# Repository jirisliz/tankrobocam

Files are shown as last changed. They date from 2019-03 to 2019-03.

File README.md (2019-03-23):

# TankRoboCam

Simple robotic tank with camera wifi controlled. 

## Parts

 - **DC motor driver**: L298N DC Stepper Motor Driver Module Dual H Bridge Control Board for Arduino
 - **ESP32 camera board**: M5Stack ESP32 Development Board 3D Wifi Antenna Mini Camera Module
 - **Tank chassis**: Smart Robot Tank Car Chassis Kit Rubber Track Crawler for Arduino 130 Motor
 - **DC-DC Step up**: MT3608 2A DC-DC Step Up Power Apply Module Booster Power Module for Arduino
 - **Arduino MCU**: Mini/Nano ATmega328P/ATmega168P CH340G/FT232 3.3/5V micro-controller Arduino

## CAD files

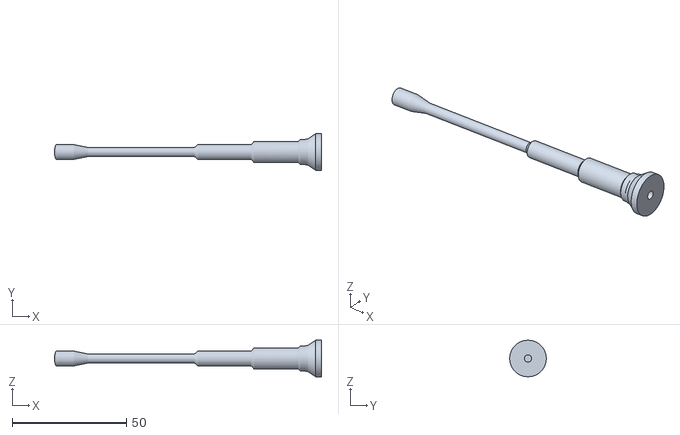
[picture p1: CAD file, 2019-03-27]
3d/Cannon.stl
116.9 x 16.0 x 16.0

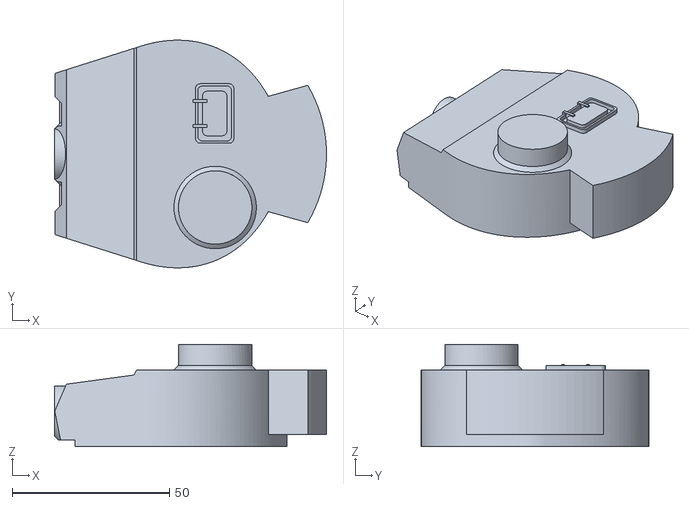
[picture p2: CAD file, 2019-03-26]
3d/Tower.stl
86.5 x 72.4 x 32.4

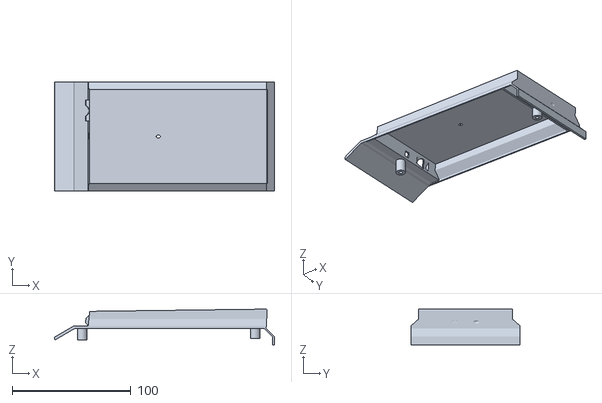
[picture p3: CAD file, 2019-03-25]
3d/RoboTankBody.stl
185.5 x 92.0 x 30.2

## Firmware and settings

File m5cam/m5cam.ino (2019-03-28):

/**
 * Based on https://github.com/mic159/m5cam
 * 
 * Reads an image from the camera and servers it to a connected client.
 * Starts a webserver and starts streaming when a client connects
 * 
 * After the device has started change your computer's WiFi to m5cam 
 * and open the browser at http://192.168.4.1 for a stream
 * or http://192.168.4.1/camera for a still picture
 */
//#define CONFIG_ENABLE_TEST_PATTERN n
#define CONFIG_OV2640_SUPPORT y
//#define CONFIG_OV7725_SUPPORT y
#define CONFIG_ESP32_DEFAULT_CPU_FREQ_240 y
#define CONFIG_ESP32_DEFAULT_CPU_FREQ_MHZ 240
#define CONFIG_MEMMAP_SMP y
#define CONFIG_TASK_WDT n
#define CONFIG_LOG_DEFAULT_LEVEL_INFO y
#define CONFIG_LOG_DEFAULT_LEVEL 3
#define CONFIG_D0 17
#define CONFIG_D1 35
#define CONFIG_D2 34
#define CONFIG_D3 5
#define CONFIG_D4 39
#define CONFIG_D5 18
#define CONFIG_D6 36
#define CONFIG_D7 19
#define CONFIG_XCLK 27
#define CONFIG_PCLK 21
#define CONFIG_VSYNC 22
#define CONFIG_HREF 26
#define CONFIG_SDA 25
#define CONFIG_SCL 23
#define CONFIG_RESET 15
#define CONFIG_XCLK_FREQ 20000000
#define CAMERA_PIXEL_FORMAT CAMERA_PF_JPEG
#define CAMERA_FRAME_SIZE CAMERA_FS_QVGA
#define CAMERA_LED_GPIO 17


#include <WiFi.h>
#include <esp_wifi.h>
#include <lwip/err.h>
#include <lwip/sockets.h>
#include "camera.h"
#include "canvas_htm.h"
#include <WebSocketsServer.h>
#include <SoftwareSerial.h>

#define RXD2 12
#define TXD2 16   // Instead of LED

IPAddress apIP(192, 168, 4, 1);

const char* ssid     = "TankRobot-192.168.4.1";
const char* pass     = "prahasucks";

WebSocketsServer webSocket = WebSocketsServer(443);
WiFiServer server(80);

SoftwareSerial SWSeral2(RXD2, TXD2);

void stopMotors()
{
  SWSeral2.printf("stop-#");
}

void webSocketEvent(uint8_t num, WStype_t type, uint8_t * payload, size_t length) {

  switch (type) {
    case WStype_DISCONNECTED:
      Serial.printf("[%u] Disconnected!\n", num);
      // Stop motors
      stopMotors();
      
      break;
    case WStype_CONNECTED: {
        IPAddress ip = webSocket.remoteIP(num);
        Serial.printf("[%u] Connected from %d.%d.%d.%d url: %s\n", num, ip[0], ip[1], ip[2], ip[3], payload);

        // send message to client
        webSocket.sendTXT(num, "Connected");
      }
      break;
    case WStype_TEXT:
      //Serial.printf("[%u] get Text: %s\n", num, payload);
      Serial.printf("%s\n", payload);
      SWSeral2.printf("%s\n", payload);

      break;
    case WStype_ERROR:
    case WStype_FRAGMENT_TEXT_START:
    case WStype_FRAGMENT_BIN_START:
    case WStype_FRAGMENT:
    case WStype_FRAGMENT_FIN:
      break;
  }

}

void serve()
{
  WiFiClient client = server.available();
  if (client) 
  {
    //Serial.println("New Client.");
    String currentLine = "";
    while (client.connected()) 
    {
      webSocket.loop();
      if (client.available()) 
      {
        char c = client.read();
        //Serial.write(c);
        if (c == '\n') 
        {
          if (currentLine.length() == 0) 
          {
            client.println("HTTP/1.1 200 OK");
            client.println("Content-type:text/html");
            client.println();
            client.print(canvas_htm);
            client.println();
            break;
          } 
          else 
          {
            currentLine = "";
          }
        } 
        else if (c != '\r') 
        {
          currentLine += c;
        }
        
        if(currentLine.endsWith("GET /camera"))
        {
            client.println("HTTP/1.1 200 OK");
            client.println("Content-type:image/jpeg");
            client.println();

              esp_err_t err = camera_run();
              if (err != ESP_OK) {
                  ESP_LOGW(TAG, "Camera capture failed with error = %d", err);
                  return;
              }
            
              size_t frame_size = camera_get_data_size();
              uint8_t* fb = camera_get_fb();
            

              client.write(fb, frame_size);
              

        }
      }
    }
    // close the connection:
    client.stop();
    //Serial.println("Client Disconnected.");
  }  
}



static camera_pixelformat_t s_pixel_format;
bool video_running = false;

int udp_server = -1;
struct sockaddr_in destination;

void setup() {
  esp_log_level_set("camera", ESP_LOG_DEBUG);
  Serial.begin(115200);
  SWSeral2.begin(9600);
  esp_err_t err;

  ESP_ERROR_CHECK(gpio_install_isr_service(0));
  //pinMode(CAMERA_LED_GPIO, OUTPUT);
  //digitalWrite(CAMERA_LED_GPIO, LOW);
  Serial.println("Camera LED init.");
  
  WiFi.disconnect(true);

  camera_config_t camera_config;
  camera_config.ledc_channel = LEDC_CHANNEL_0;
  camera_config.ledc_timer = LEDC_TIMER_0;
  camera_config.pin_d0 = CONFIG_D0;
  camera_config.pin_d1 = CONFIG_D1;
  camera_config.pin_d2 = CONFIG_D2;
  camera_config.pin_d3 = CONFIG_D3;
  camera_config.pin_d4 = CONFIG_D4;
  camera_config.pin_d5 = CONFIG_D5;
  camera_config.pin_d6 = CONFIG_D6;
  camera_config.pin_d7 = CONFIG_D7;
  camera_config.pin_xclk = CONFIG_XCLK;
  camera_config.pin_pclk = CONFIG_PCLK;
  camera_config.pin_vsync = CONFIG_VSYNC;
  camera_config.pin_href = CONFIG_HREF;
  camera_config.pin_sscb_sda = CONFIG_SDA;
  camera_config.pin_sscb_scl = CONFIG_SCL;
  camera_config.pin_reset = CONFIG_RESET;
  camera_config.xclk_freq_hz = CONFIG_XCLK_FREQ;

  camera_model_t camera_model;
  err = camera_probe(&camera_config, &camera_model);
  if (err != ESP_OK) {
      ESP_LOGE(TAG, "Camera probe failed with error 0x%x", err);
      return;
  }

  if (camera_model == CAMERA_OV7725) {
      s_pixel_format = CAMERA_PIXEL_FORMAT;
      camera_config.frame_size = CAMERA_FRAME_SIZE;
      ESP_LOGI(TAG, "Detected OV7725 camera, using %s bitmap format",
              CAMERA_PIXEL_FORMAT == CAMERA_PF_GRAYSCALE ?
                      "grayscale" : "RGB565");
  } else if (camera_model == CAMERA_OV2640) {
      ESP_LOGI(TAG, "Detected OV2640 camera, using JPEG format");
      s_pixel_format = CAMERA_PF_JPEG;
      camera_config.frame_size = CAMERA_FRAME_SIZE;
      camera_config.jpeg_quality = 15;
  } else {
      ESP_LOGE(TAG, "Camera not supported");
      return;
  }
  Serial.println("Camera selected.");

  camera_config.pixel_format = s_pixel_format;
  err = camera_init(&camera_config);
  if (err != ESP_OK) {
      ESP_LOGE(TAG, "Camera init failed with error 0x%x", err);
      return;
  }
  Serial.println("Camera init.");

  ESP_LOGI("Starting WiFi AP m5cam");

  WiFi.mode(WIFI_AP);
  WiFi.softAPConfig(apIP, apIP, IPAddress(255, 255, 255, 0));
  WiFi.softAP(ssid, pass);

  webSocket.begin();
  webSocket.onEvent(webSocketEvent);
  Serial.println("Websockets server started");

  Serial.print("IP address: ");
  Serial.println(WiFi.softAPIP());

  server.begin();
  
  stopMotors();
}

unsigned long previousMillis = 0;
void loop() {
  serve();
}

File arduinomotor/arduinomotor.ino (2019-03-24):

#include "motors.h"

// HW serial port Serial1 pins RX D0 and TX D1 (only RX is realy used)

void setup()
{
  Serial.begin(9600); //This pipes to the serial monitor
  Serial1.begin(9600);

  motorsInit();
}

String cmd;

void loop()
{
  while (Serial.available()) {
    char c = Serial.read();
    cmd += c;
    if (c == '\n')
    {
      parseCmd(cmd);
      cmd = "";
    }
  }

}

/**
   Parses and executes command in form <command>-<value>#
*/
void parseCmd(String cmd)
{
  String strCmd;
  String strValue;
  if(cmd.indexOf("-") > 0)
  {
    strCmd = cmd.substring(0, cmd.indexOf("-"));
    strValue = cmd.substring(cmd.indexOf("-") + 1, cmd.indexOf("\n"));
  }
  else if(cmd.indexOf("\n") > 0)
  {
    strCmd = cmd.substring(0, cmd.indexOf("#"));
  }
  else return;
  
  Serial.println("strCmd: " + strCmd);
  Serial.println("strValue: " + strValue);

  
    if (strCmd.indexOf("LF") >= 0)
    {
    leftMotorForward(strValue.toInt());
    Serial.print(cmd);
    }
    if (strCmd.indexOf("LB") >= 0)
    {
    leftMotorBackward(strValue.toInt());
    Serial.print(cmd);
    }
    if (strCmd.indexOf("RF") >= 0)
    {
    rightMotorForward(strValue.toInt());
    Serial.print(cmd);
    }
    if (strCmd.indexOf("RB") >= 0)
    {
    rightMotorBackward(strValue.toInt());
    Serial.print(cmd);
    }
    if (strCmd.indexOf("stop") >= 0)
    {
    motorsStop();
    Serial.print(cmd);
    }
  

}

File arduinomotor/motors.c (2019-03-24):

#include "motors.h"

void motorsInit()
{
  pinMode(LMF, OUTPUT);
  pinMode(LMB, OUTPUT);
  pinMode(RMF, OUTPUT);
  pinMode(RMB, OUTPUT);
  motorsStop();
}

void motorsStop()
{
  digitalWrite(LMF, LOW);
  digitalWrite(LMB, LOW);
  digitalWrite(RMF, LOW);
  digitalWrite(RMB, LOW);
}

void leftMotorForward(int aPwm)
{
  analogWrite(LMF, aPwm);
  digitalWrite(LMB, LOW);
}

void leftMotorBackward(int aPwm)
{
  analogWrite(LMB, aPwm);
  digitalWrite(LMF, LOW);
}

void rightMotorForward(int aPwm)
{
  analogWrite(RMF, aPwm);
  digitalWrite(RMB, LOW);
}

void rightMotorBackward(int aPwm)
{
  analogWrite(RMB, aPwm);
  digitalWrite(RMF, LOW);
}

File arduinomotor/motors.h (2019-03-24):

#pragma once

#include <arduino.h>

// Robot motors pwm outputs
#define LMF 6  // Left Motor Forward
#define LMB 5  // Left Motor Backward
#define RMF 9  // Right Motor Forward
#define RMB 10 // Right Motor Backward

#ifdef __cplusplus
extern "C" {
#endif

void motorsInit();
void motorsStop();
void leftMotorForward(int aPwm);
void leftMotorBackward(int aPwm);
void rightMotorForward(int aPwm);
void rightMotorBackward(int aPwm);

#ifdef __cplusplus
}
#endif

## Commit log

2019-03-20 added camera stream project based on: https://github.com/squix78/m5cam
2019-03-23 softwareserial port test added - LED output used because groove connector pins are connected somewhere
2019-03-23 arduino micro code template created
2019-03-24 basic motor test with serial port from PC (Serial1 will be used at the end)
2019-03-24 added htmlto h and vice versa python converter from: https://github.com/CoretechR/ESP32-WiFi-Robot also basic html added with joystick support
2019-03-25 camera image rotated 180 deg in html
2019-03-25 first try robot tank body
    [RoboTankBody.stl]
2019-03-26 websockets joystick communication estabilished, but better motors command calcuation stil needed
2019-03-26 tower and cannon 3d models added
    [Cannon.stl, Tower.stl]
2019-03-27 larger diameter to better print canon
    [Cannon.stl]
2019-03-28 joystick to motors speed convertion finished. Websockets commented for testing on PC
2019-03-28 stop on disconect and reset, selected speed range in html
    [m5cam.ino]
